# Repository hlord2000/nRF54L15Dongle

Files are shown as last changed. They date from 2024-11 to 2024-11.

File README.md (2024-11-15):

# nRF54L15 Dongle
<p align="center">
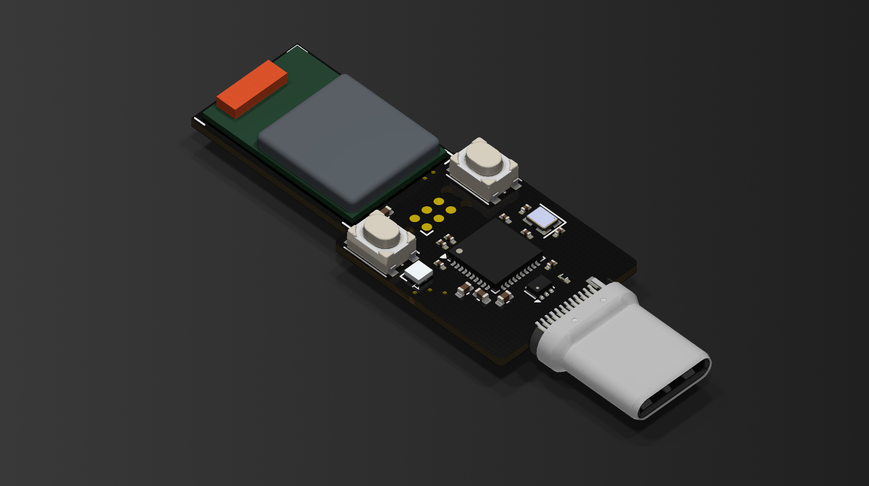
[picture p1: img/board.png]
nRF54L15 Dongle
  
</p>

High-performance BLE development dongle featuring Nordic's nRF54L15 SoC with integrated nRF52833-based debugger.

## Hardware

- nRF54L15 SoC with BLE 6.0 and 4Mbps proprietary PHY
- Integrated nRF52833 as pyOCD debugger and UART-USB bridge
- USB Type-C plug for direct computer connection
- RGB LED and dual buttons (reset + user/bootloader)

## Features

- Onboard debugging eliminates external tools
- Concurrent debug and serial bridge operation
- High-throughput 4Mbps proprietary radio mode
- Compact plug-in form factor

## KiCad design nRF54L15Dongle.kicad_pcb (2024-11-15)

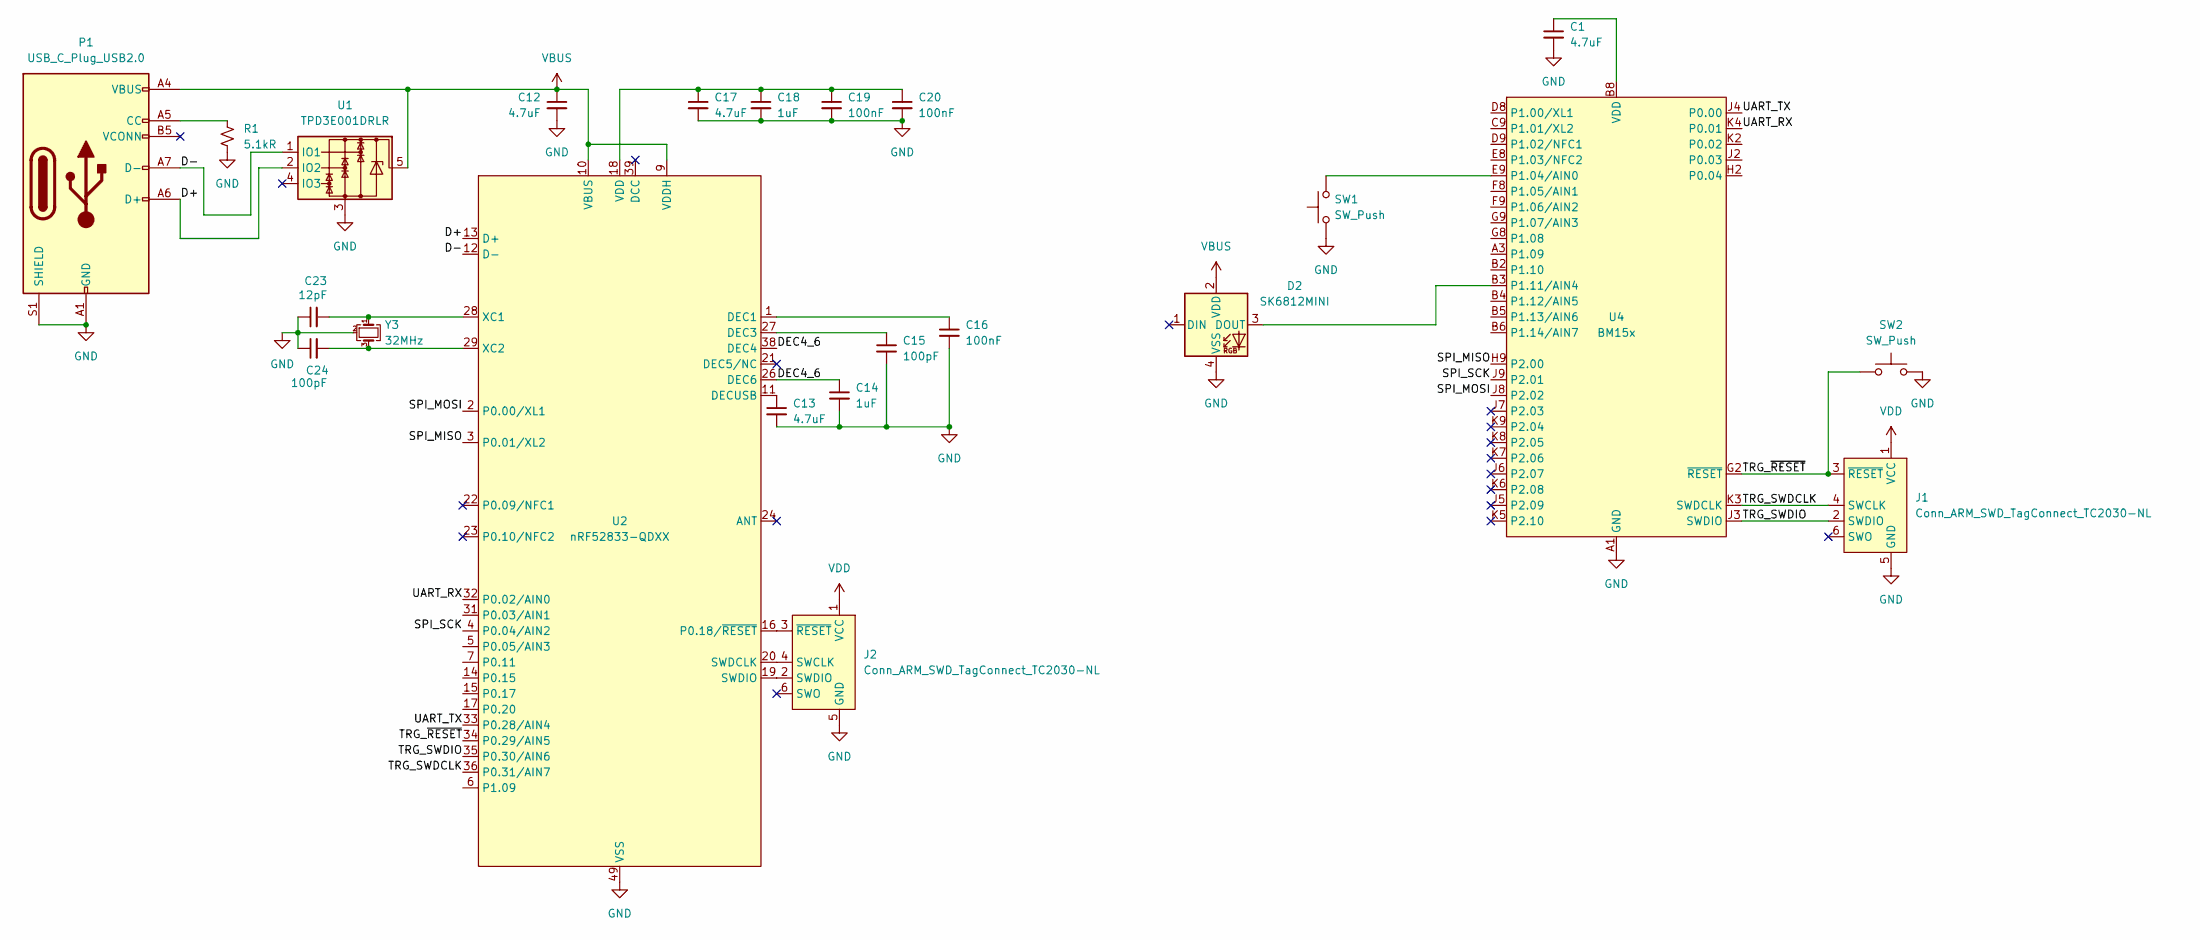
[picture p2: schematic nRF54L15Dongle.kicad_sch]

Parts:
C1, C12, C13, C17: 4.7uF; C_0402_1005Metric
C14, C18: 1uF; C_0201_0603Metric
C15, C24: 100pF; C_0201_0603Metric
C16, C19, C20: 100nF; C_0201_0603Metric
C23: 12pF; C_0201_0603Metric
D2: SK6812MINI; LED_SK6812_EC15_1.5x1.5mm; LCSC C2890035
J1, J2: Conn_ARM_SWD_TagConnect_TC2030-NL; Tag-Connect_TC2030-IDC-NL_2x03_P1.27mm_Vertical
P1: USB_C_Plug_USB2.0; USB_C_Plug_Molex_105444; LCSC C134082
R1: 5.1kR; R_0201_0603Metric
SW1, SW2: SW_Push; SW_Push_1P1T_NO_Vertical_Wuerth_434133025816
U1: TPD3E001DRLR; SOT-553
U2: nRF52833-QDXX; QFN-40-1EP_5x5mm_P0.4mm_EP3.6x3.6mm
U4: BM15x; BM15x-LGA-45_15.8x10mm
Y3: 32MHz; Crystal_SMD_2016-4Pin_2.0x1.6mm

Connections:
/D+: P1.A6 (D+), U1.2 (IO2), U2.13 (D+)
/D-: P1.A7 (D-), U1.1 (IO1), U2.12 (D-)
/DEC4_6: C14.1, U2.26 (DEC6), U2.38 (DEC4)
/SPI_MISO: U2.3 (P0.01/XL2), U4.H9 (P2.00)
/SPI_MOSI: U2.2 (P0.00/XL1), U4.J8 (P2.02)
/SPI_SCK: U2.4 (P0.04/AIN2), U4.J9 (P2.01)
/TRG_SWDCLK: J1.4 (SWCLK), U2.36 (P0.31/AIN7), U4.K3 (SWDCLK)
/TRG_SWDIO: J1.2 (SWDIO), U2.35 (P0.30/AIN6), U4.J3 (SWDIO)
/TRG_~RESET: J1.3 (~RESET), SW2.1, U2.34 (P0.29/AIN5), U4.G2 (~RESET)
/UART_RX: U2.32 (P0.02/AIN0), U4.K4 (P0.01)
/UART_TX: U2.33 (P0.28/AIN4), U4.J4 (P0.00)
GND: C1.2, C12.2, C13.2, C14.2, C15.2, C16.2, C17.2, C18.2, C19.2, C20.2, C23.1, C24.1, D2.4 (VSS), J1.5 (GND), J2.5 (GND), P1.A1 (GND), P1.A12 (GND), P1.B1 (GND), P1.B12 (GND), P1.S1 (SHIELD), R1.2, SW1.1, SW2.2, U1.3, U2.25 (VSS_PA), U2.37 (VSS), U2.49 (VSS), U4.A1 (GND), U4.A9 (GND), U4.B1 (GND), U4.B7 (GND), U4.B9 (GND), U4.D1 (GND), U4.E1 (GND), U4.F1 (GND), U4.H8 (GND), Y3.2, Y3.4
unnamed: C1.1, U4.B8 (VDD), U4.C8 (VDD)
unnamed: C17.1, C18.1, C19.1, C20.1, U2.8 (VDD), U2.18 (VDD), U2.30 (VDD), U2.40 (VDD)
unnamed: D2.3 (DOUT), U4.B3 (P1.11/AIN4)
unnamed: J2.4 (SWCLK), U2.20 (SWDCLK)
unnamed: J2.2 (SWDIO), U2.19 (SWDIO)
unnamed: J2.3 (~RESET), U2.16 (P0.18/~RESET)
unnamed: P1.A5 (CC), R1.1
unnamed: C16.1, U2.1 (DEC1)
unnamed: C15.1, U2.27 (DEC3)
unnamed: C13.1, U2.11 (DECUSB)
unnamed: C23.2, U2.28 (XC1), Y3.1
unnamed: C24.2, U2.29 (XC2), Y3.3
unnamed: SW1.2, U4.E9 (P1.04/AIN0)
VBUS: C12.1, D2.2 (VDD), P1.A4 (VBUS), P1.A9 (VBUS), P1.B4 (VBUS), P1.B9 (VBUS), U1.5, U2.9 (VDDH), U2.10 (VBUS)
VDD: J1.1 (VCC), J2.1 (VCC)

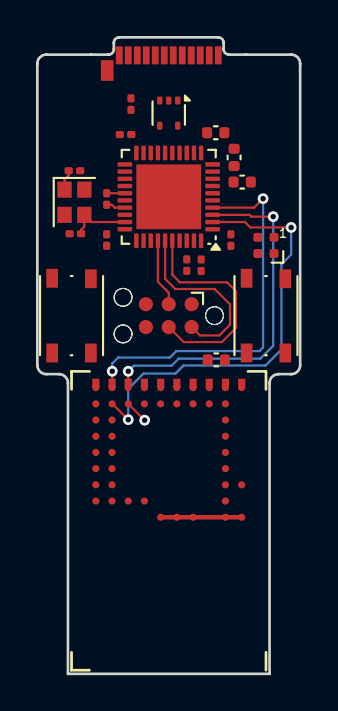
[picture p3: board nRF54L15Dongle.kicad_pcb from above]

Board: 6 copper layers, 14.6 x 35.4 mm, 23 parts (1 on the bottom side), 27 nets.
